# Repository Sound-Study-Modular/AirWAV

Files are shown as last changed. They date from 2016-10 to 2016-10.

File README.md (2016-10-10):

# Sound Study Modular AirWAV

##Information for re-use, adaptations or derivative works

Sound Study Modular is trademarked, and should not be used on any of works you create from these files.

We ask that if you want to re-use all or part of the files provided on github that you change the name of the product to something else

##What is this module?

The Sound Study Modular Air Wav is a virtual radio module, so it behaves a bit like a radio. It is designed to be a source of unexpected audio, not a drum loop player or a sample mangler.

Like a radio, this module works on a series of banks and stations. Each of the 16 banks can contain many different stations. Each station is .raw audio file stored in a bank directory on the SD card. Choose a bank by pressing and holding the RESET switch. Choose a station by turning the STATION knob or plugging a voltage into TUNE.
Detailed controls and displays
Adding samples to the SD Card

Full instructions and tools are in the <a href="http://www.soundstudymodular.com/assembly-instructions/air-wav-assembly-instructions/#sdCard">Setting up the SD Card</a> Section.

##Bank and meter LEDs

The LEDs at the top do two jobs. When audio is playing, they act as a simple VU meter. While choosing banks, they show the bank number in binary

- 0 ○○○○

- 1 ●○○○

- 2 ○●○○

- 3 ●●○○

- 4 ○○●○

- 5 ●○●○

- 6 ○●●○

- 7 ●●●○

- 8 ○○○●

- 9 ●○○●

- 10 ○●○●

- 11 ●●○●

- 12 ○○●●

- 13 ●○●●

- 14 ○●●●

- 15 ●●●●

##Station knob

This is how you choose which file to play from the current folder. It works exactly like a radio tuning knob.

You can put up to 75 files in each folder, but with that many files it might be hard to accurately tune to a station.
If you're between stations, you might get a rapid juddering sound as the module slips between stations. Just retune the knob. If you find it a big problem, put fewer files in each directory so the channels are more spaced out.
Like real radio stations, the files continue to play in the background - they don't re-trigger each time you select a new station.

##Start knob

This knob sets where the file will play from if you press the RESET button. It does nothing until you press the 'Reset' button! (This behaviour can be changed by editing settings.txt)

It's quite a coarse control, with a resolution of 512 steps. So, if you have a 30 minute radio show, the smallest shift you can make will be around 3.5 seconds. If you're playing a 4 second loop, the control will be finer.

##Reset button & LED

TAP the Reset button restarts the current track at the point determined by the Start knob or the Start CV input.

If you're playing a large file (a 30 minute .raw file is 150mb) it will take a few milliseconds to skip to the end of the file, so the button feels less responsive than it does with smaller files, or the earlier parts of bigger files.

HOLD the Reset button for more than 200ms to change banks. Keep the button held down to skip through all 16 banks.

Bank position is saved on the module after power-down.

##SD Card Slot

Full details of the SD file structure are here: <a href="http://www.soundstudymodular.com/assembly-instructions/air-wav-assembly-instructions/#sdCard">SD Card Details</a>

It's possible to hot-swap SD cards. If the module detects the SD card has been removed, it will reboot. When the module boots up, it looks for an SD card for a while - the bank LEDs flash when no card is present. After a while it will give up, and you'll need to turn the power on and off.

##Tune CV Input

This is the CV equivalent of the Station Pot. If the CV changes, the module will immediately re-tune to the relevant station.

The module 'understands' 0v to +5v signals, and is protected against higher or negative voltages.
The CV input is added to the knob position; if the knob is at 12 o'clock and 2.5v is applied to the CV, it's the equivalent of the knob being fully clockwise. Unfortunately you can't 'pull the pot down' by applying a negative voltage.

##Start CV input

This is the CV equivalent of the Start pot. Like the start pot, it does nothing until a 'Reset' CV is received. This CV input behaves like the Tune CV - it's zero to +5v, added to the pot position.
Reset Trigger input

A positive clock here triggers the reset button. It should not trigger the bank change.
##Output

This is a normal modular-level audio output.

The output level is set by the trimmer on the back of the module

The output is AC-coupled so cannot output control voltages

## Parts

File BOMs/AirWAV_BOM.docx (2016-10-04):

# Control Board

Resistors:

QTY | Value | Ref. | Mouser Part #
2 | ‎220Ω | R17, R18 | 291-220-RC
5 | 1.5kΩ | R11, R12, R13, R14, R15 | 291-1.5k-RC
1 | 10kΩ | R8 | 291-10k-RC
2 | 22kΩ | R9, R20 | 291-22k-RC
2 | 47kΩ | R10, R21 | 291-47k-RC
1 | 100kΩ | R19 | 291-100k-RC

TOTAL: 13

Diodes:

QTY | Value | Ref. | Mouser Part #
5 | 3mm Red LED | LED1, LED2, LED3, LED4, LED5 | 604-WP710A10GD
2 | BAT85 | D7, D8 | 78-BAT85S

TOTAL: 7

Potentiometers:

QTY | Value | Ref. | Mouser Part #
2 | B50kΩ | TIME-POT, CHANNEL-POT | Various Suppliers

TOTAL: 2

Jacks/Switches:

QTY | Value | Ref. | Mouser Part #
4 | 3.5mm Mono PJ-301BM-12 Vertical Mount Jack | RESET-CV, TIME-CV, OUTPUT, CHANNEL-CV | PJ301M-12 (Synthrotek or Thonk)
1 | Vertical SD Card Holder | X1 | 945-PJS008U-3000-0
1 | Push Button | RESET | 611-D6R60F1LFS
1 | 11x1 Male Header | JP2 | Synthrotek
1 | 7x1 Male Header | JP4 | Synthrotek

TOTAL: 8

Other:

QTY | Value | Ref. | Mouser Part #
2 | 2.5mm x 6mm Screws | N/A | Synthrotek
2 | 3mm x 6mm Screws | N/A | Synthrotek
1 | PCB & Panel | N/A | Synthrotek
1 | 10 - 16 Pin Power Cable | N/A | Synthrotek

TOTAL: 6

# Logic Board

Resistors:

QTY | Value | Ref. | Mouser Part #
2 | 47Ω | R1, R2 | 291-47-RC
1 | 1kΩ | R7 | 291-1k-RC
2 | 8.2kΩ | R3, R4 | 291-8.2k-RC
1 | 330kΩ | R5 | 291-330k-RC

TOTAL: 6

Diodes:

QTY | Value | Ref. | Mouser Part #
4 | BAT85 | D1, D2, D3, D4 | 78-BAT85S
2 | 1N4002 | D5, D6 | 863-1N4002G

TOTAL: 6

Capacitors:

QTY | Value | Ref. | Mouser Part #
2 | 1nF Ceramic | C1, C4 | 140-50P2-102K-RC
4 | 100nF Ceramic | C2, C3, C5, C8 | 140-50V5-104Z-RC
2 | 10μF Electrolytic | C6, C7 | 667-ECE-A1CKA100

TOTAL: 8

Integrated Circuits:

QTY | Value | Ref. | Mouser Part #
1 | LM78L05 | IC1 | 512-LM78L05ACZ
1 | TL074 | IC4 | 595-TL074CN
1 | 14 Pin DIP Socket | IC4 | 571-1-2199298-3

TOTAL: 3

Potentiometers:

QTY | Value | Ref. | Mouser Part #
1 | B50kΩ Small Box Trimmer | OUTPUT VOLUME | 652-3362P-1-503LF

TOTAL: 1

Jacks/Switches:

QTY | Value | Ref. | Mouser Part #
1 | 11x1 Socket | JP1 | Synthrotek
1 | 7x1 Socket | JP3 | Synthrotek
1 | 14x1 Socket | See Assembly Instructions | Synthrotek
1 | 13x1 Socket | See Assembly Instructions | Synthrotek
1 | 2x1 Socket | See Assembly Instructions | Synthrotek
1 | 14x1 Header | See Assembly Instructions | Synthrotek
1 | 13x1 Header | See Assembly Instructions | Synthrotek
1 | 2x1 Header | See Assembly Instructions | Synthrotek
1 | 5x2 Unshrouded Male Header | POWER | Synthrotek

TOTAL: 6

Other:

QTY | Value | Ref. | Mouser Part #
2 | 200mA Fuse | F1, F2 | 652-MFR020-LF
2 | BL01RNA Ferrite Bead | L1, L2 | 81-BL01RN1A1D2B
1 | Teensy 3.0, 3.1, or 3.2 | TEENSY 3.0, 3.1, or 3.2

TOTAL: 5

Air WAV BOM Updated: 09.07.2016

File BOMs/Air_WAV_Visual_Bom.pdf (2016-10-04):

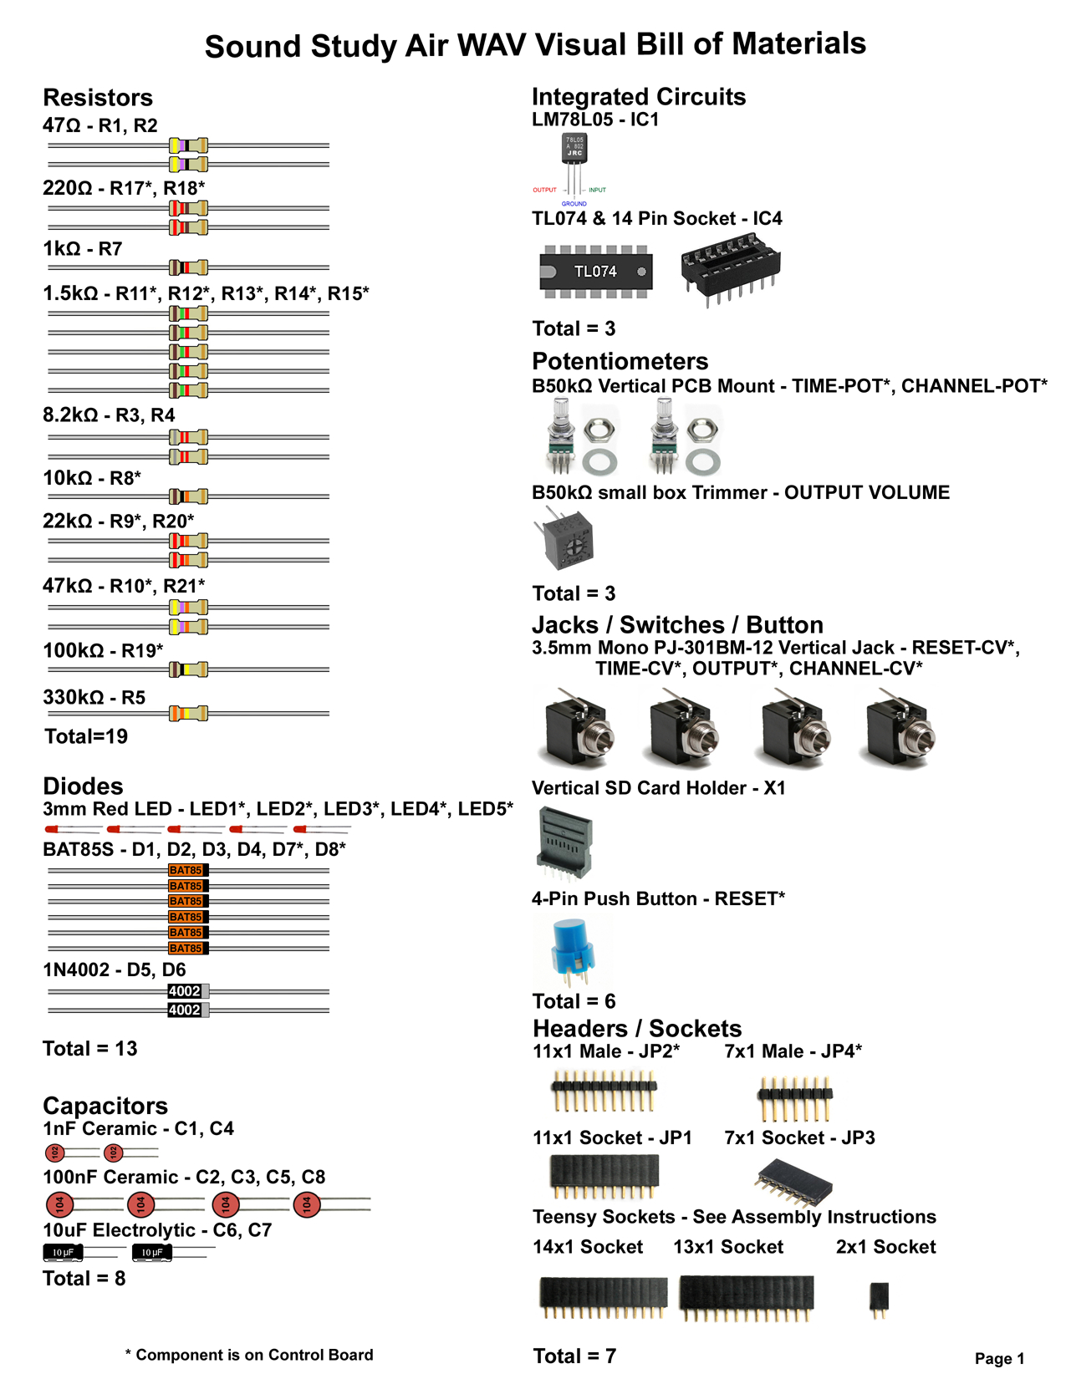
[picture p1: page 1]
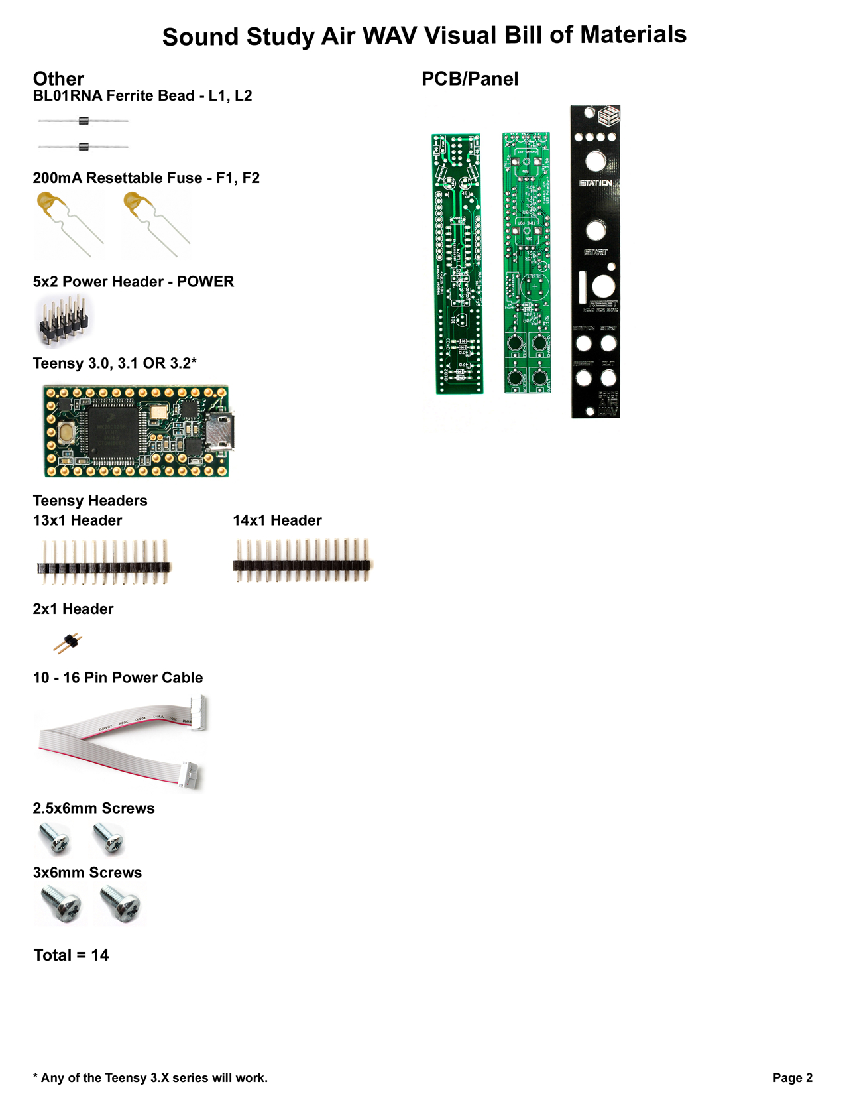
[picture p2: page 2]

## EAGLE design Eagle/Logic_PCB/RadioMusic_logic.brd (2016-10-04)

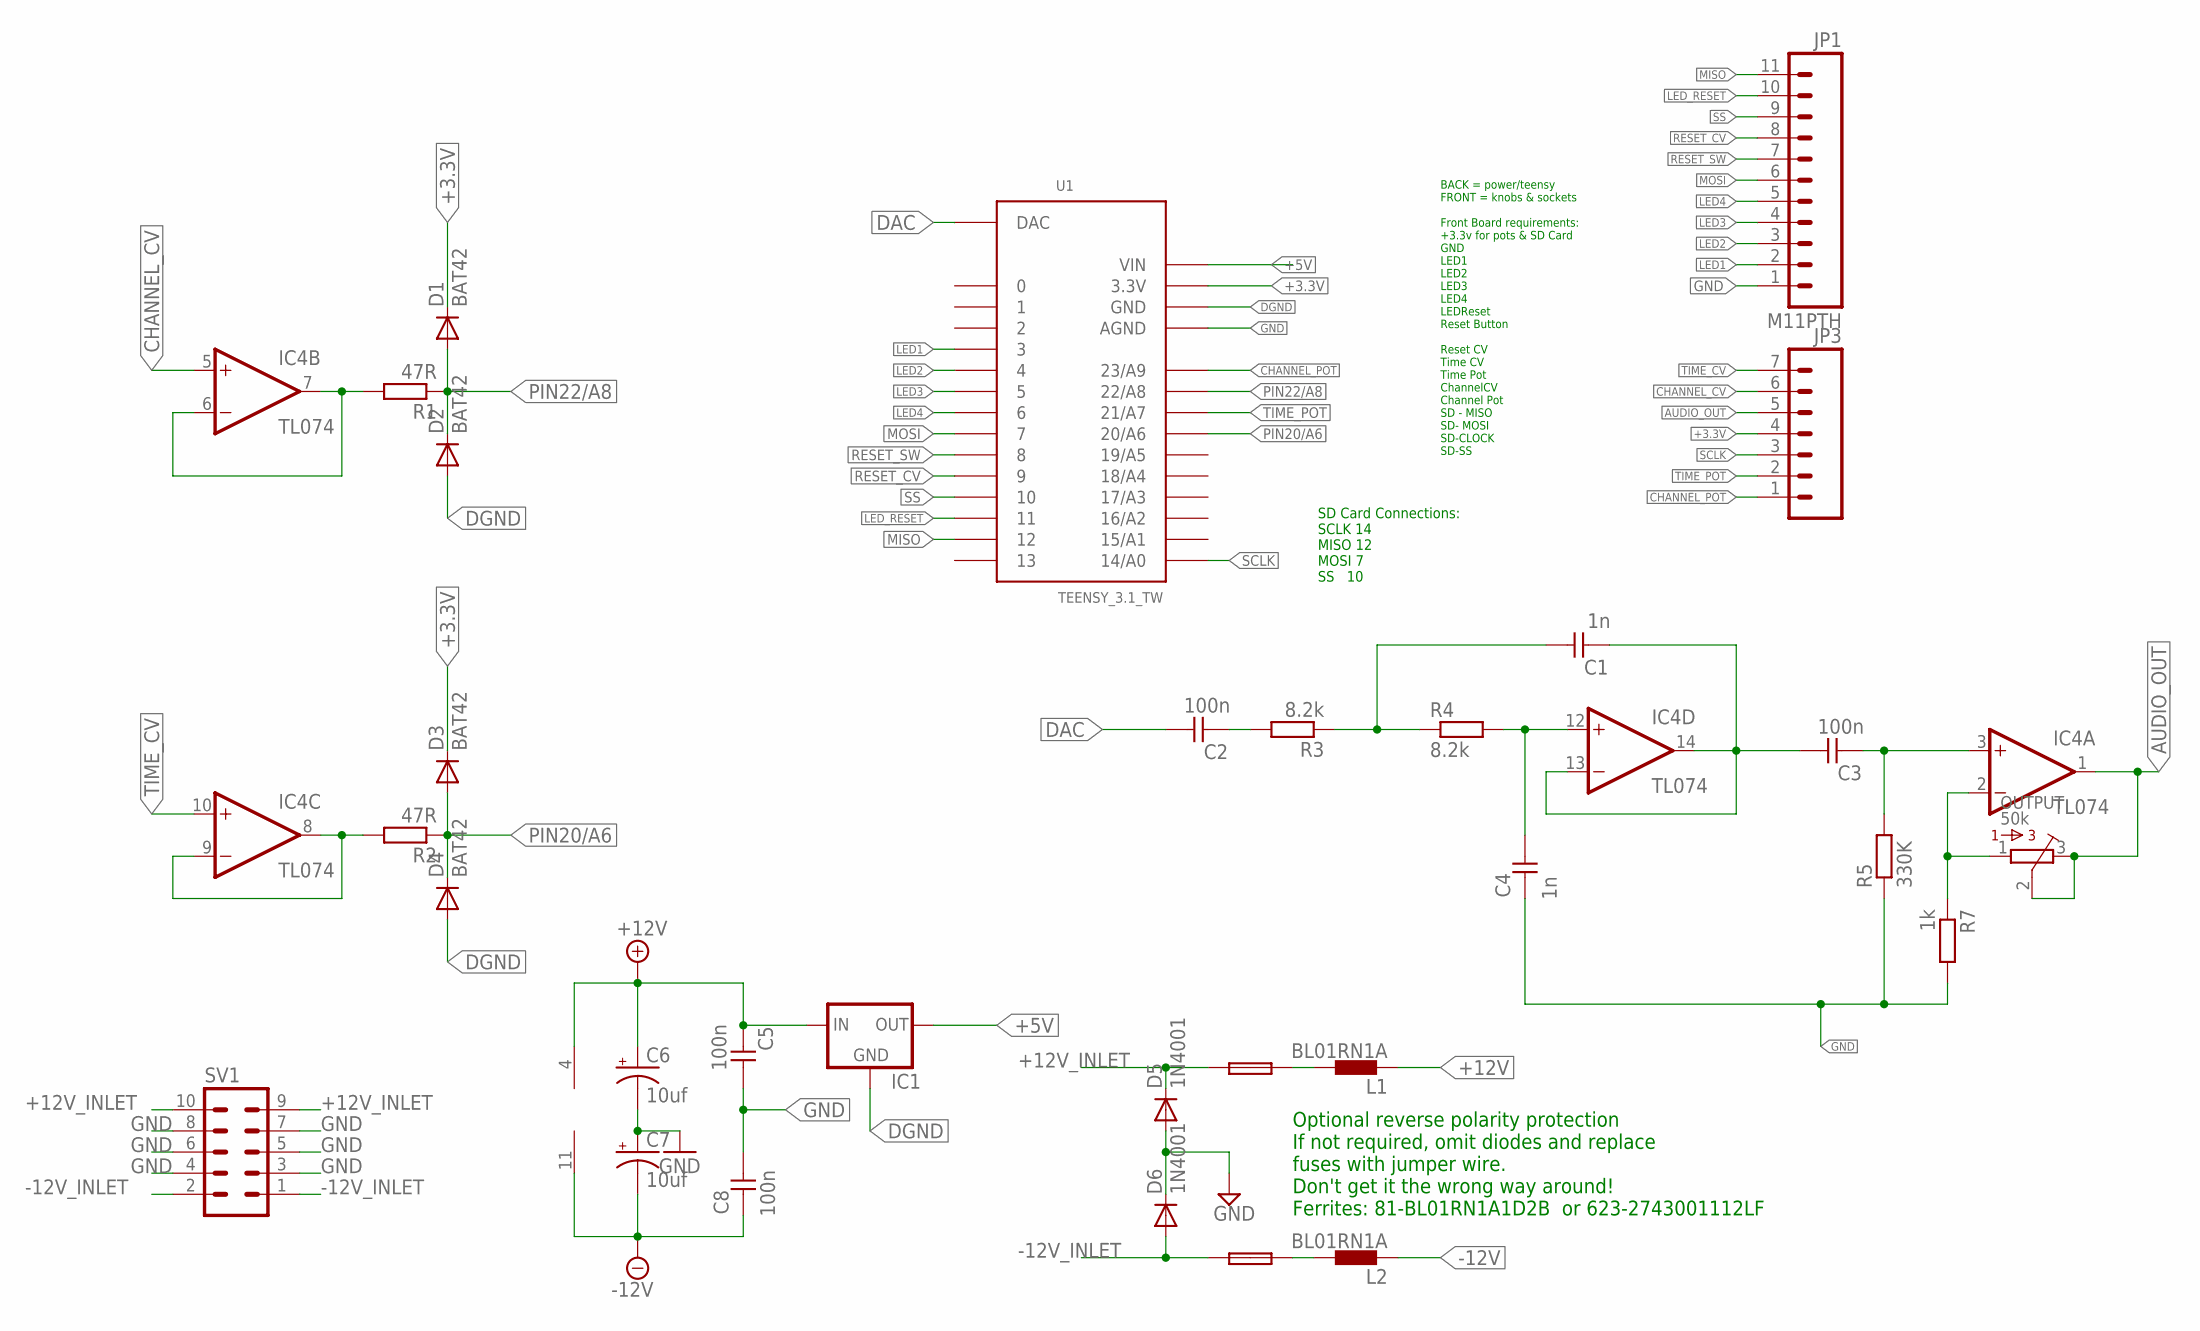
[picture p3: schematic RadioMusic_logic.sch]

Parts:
C1, C4: 1n; C050-024X044
C2, C3: 100n; C050-025X075
C5, C8: 100n; C050-024X044
C6, C7: 10uf; CPOL-RADIAL-10UF-25V
D1, D2, D3, D4: BAT42; DO34-7
D5, D6: 1N4001; DO41-10
F1, F2: FUSE; C050H075X075
IC1: 78LXX
IC4: TL074; DIL14
JP1: M11PTH; 1X11
JP3: M07; 1X07
L1, L2: BL01RN1A
OUTPUT: 50k; 3362P
R1, R2: 47R; 0207/10
R3, R4: 8.2k; 0207/10
R5: 330K; 0207/10
R7: 1k; 0207/10
SV1: 10_PIN_HEADER; MA05-2
U1: TEENSY_3.1_TW

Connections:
+3.3V: D1.C, D3.C, JP3.4, U1.3.3V
+5V: IC1.OUT, U1.VIN
+12V: C5.2, C6.1 (+), IC1.IN, IC4.4 (V+), L1.1
+12V_INLET: D5.C, F1.1, SV1.9, SV1.10
-12V: C7.2 (-), C8.2, IC4.11 (V-), L2.1
-12V_INLET: D6.A, F2.1, SV1.1, SV1.2
AUDIO_OUT: IC4.1 (OUT), JP3.5, OUTPUT.2, OUTPUT.3
CHANNEL_CV: IC4.5 (+IN), JP3.6
CHANNEL_POT: JP3.1, U1.23/A9
DAC: C2.1, U1.DAC
DGND: D2.A, D4.A, IC1.GND, U1.GND
GND: C4.2, C5.1, C6.2 (-), C7.1 (+), C8.1, D5.A, D6.C, JP1.1, R5.1, R7.2, SV1.3, SV1.4, SV1.5, SV1.6, SV1.7, SV1.8, U1.AGND
LED1: JP1.2, U1.3
LED2: JP1.3, U1.4
LED3: JP1.4, U1.5
LED4: JP1.5, U1.6
LED_RESET: JP1.10, U1.11
MISO: JP1.11, U1.12
MOSI: JP1.6, U1.7
unnamed: IC4.8 (OUT), IC4.9 (-IN), R2.2
unnamed: C4.1, IC4.12 (+IN), R4.2
unnamed: IC4.6 (-IN), IC4.7 (OUT), R1.2
unnamed: C1.1, R3.1, R4.1
unnamed: C1.2, C3.1, IC4.13 (-IN), IC4.14 (OUT)
unnamed: C3.2, IC4.3 (+IN), R5.2
unnamed: IC4.2 (-IN), OUTPUT.1, R7.1
unnamed: C2.2, R3.2
unnamed: F1.2, L1.2
unnamed: F2.2, L2.2
PIN20/A6: D3.A, D4.C, R2.1, U1.20/A6
PIN22/A8: D1.A, D2.C, R1.1, U1.22/A8
RESET_CV: JP1.8, U1.9
RESET_SW: JP1.7, U1.8
SCLK: JP3.3, U1.14/A0
SS: JP1.9, U1.10
TIME_CV: IC4.10 (+IN), JP3.7
TIME_POT: JP3.2, U1.21/A7

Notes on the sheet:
Optional reverse polarity protection If not required, omit diodes and replace fuses with jumper wire. Don't get it the wrong way around! Ferrites: 81-BL01RN1A1D2B or 623-2743001112LF
SD Card Connections: SCLK 14 MISO 12 MOSI 7 SS 10
BACK = power/teensy FRONT = knobs & sockets Front Board requirements: +3.3v for pots & SD Card GND LED1 LED2 LED3 LED4 LEDReset Reset Button Reset CV Time CV Time Pot ChannelCV Channel Pot SD - MISO SD- MOSI SD-CLOCK SD-SS

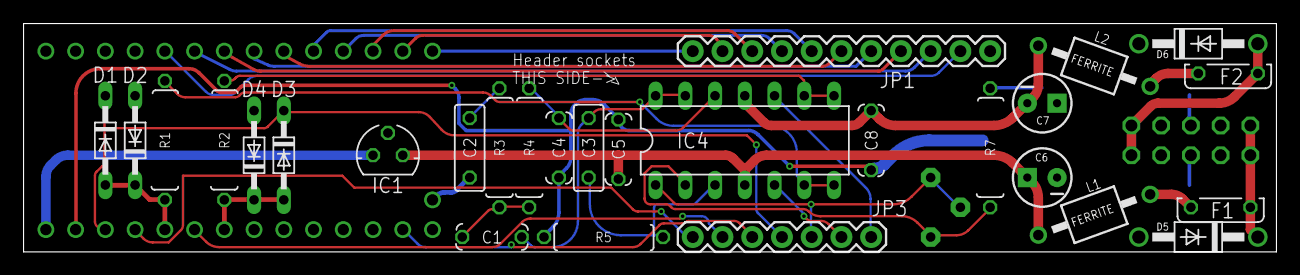
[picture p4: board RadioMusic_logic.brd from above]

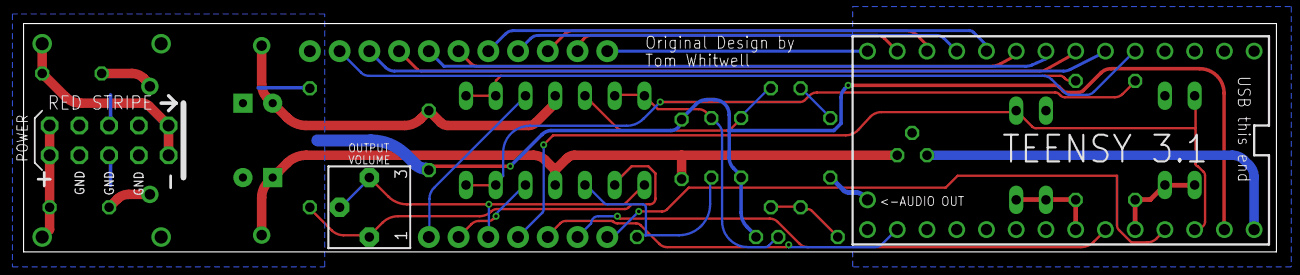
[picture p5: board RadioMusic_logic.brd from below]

Board: 4 copper layers, 107.0 x 19.5 mm, 31 parts (3 on the bottom side), 37 nets.

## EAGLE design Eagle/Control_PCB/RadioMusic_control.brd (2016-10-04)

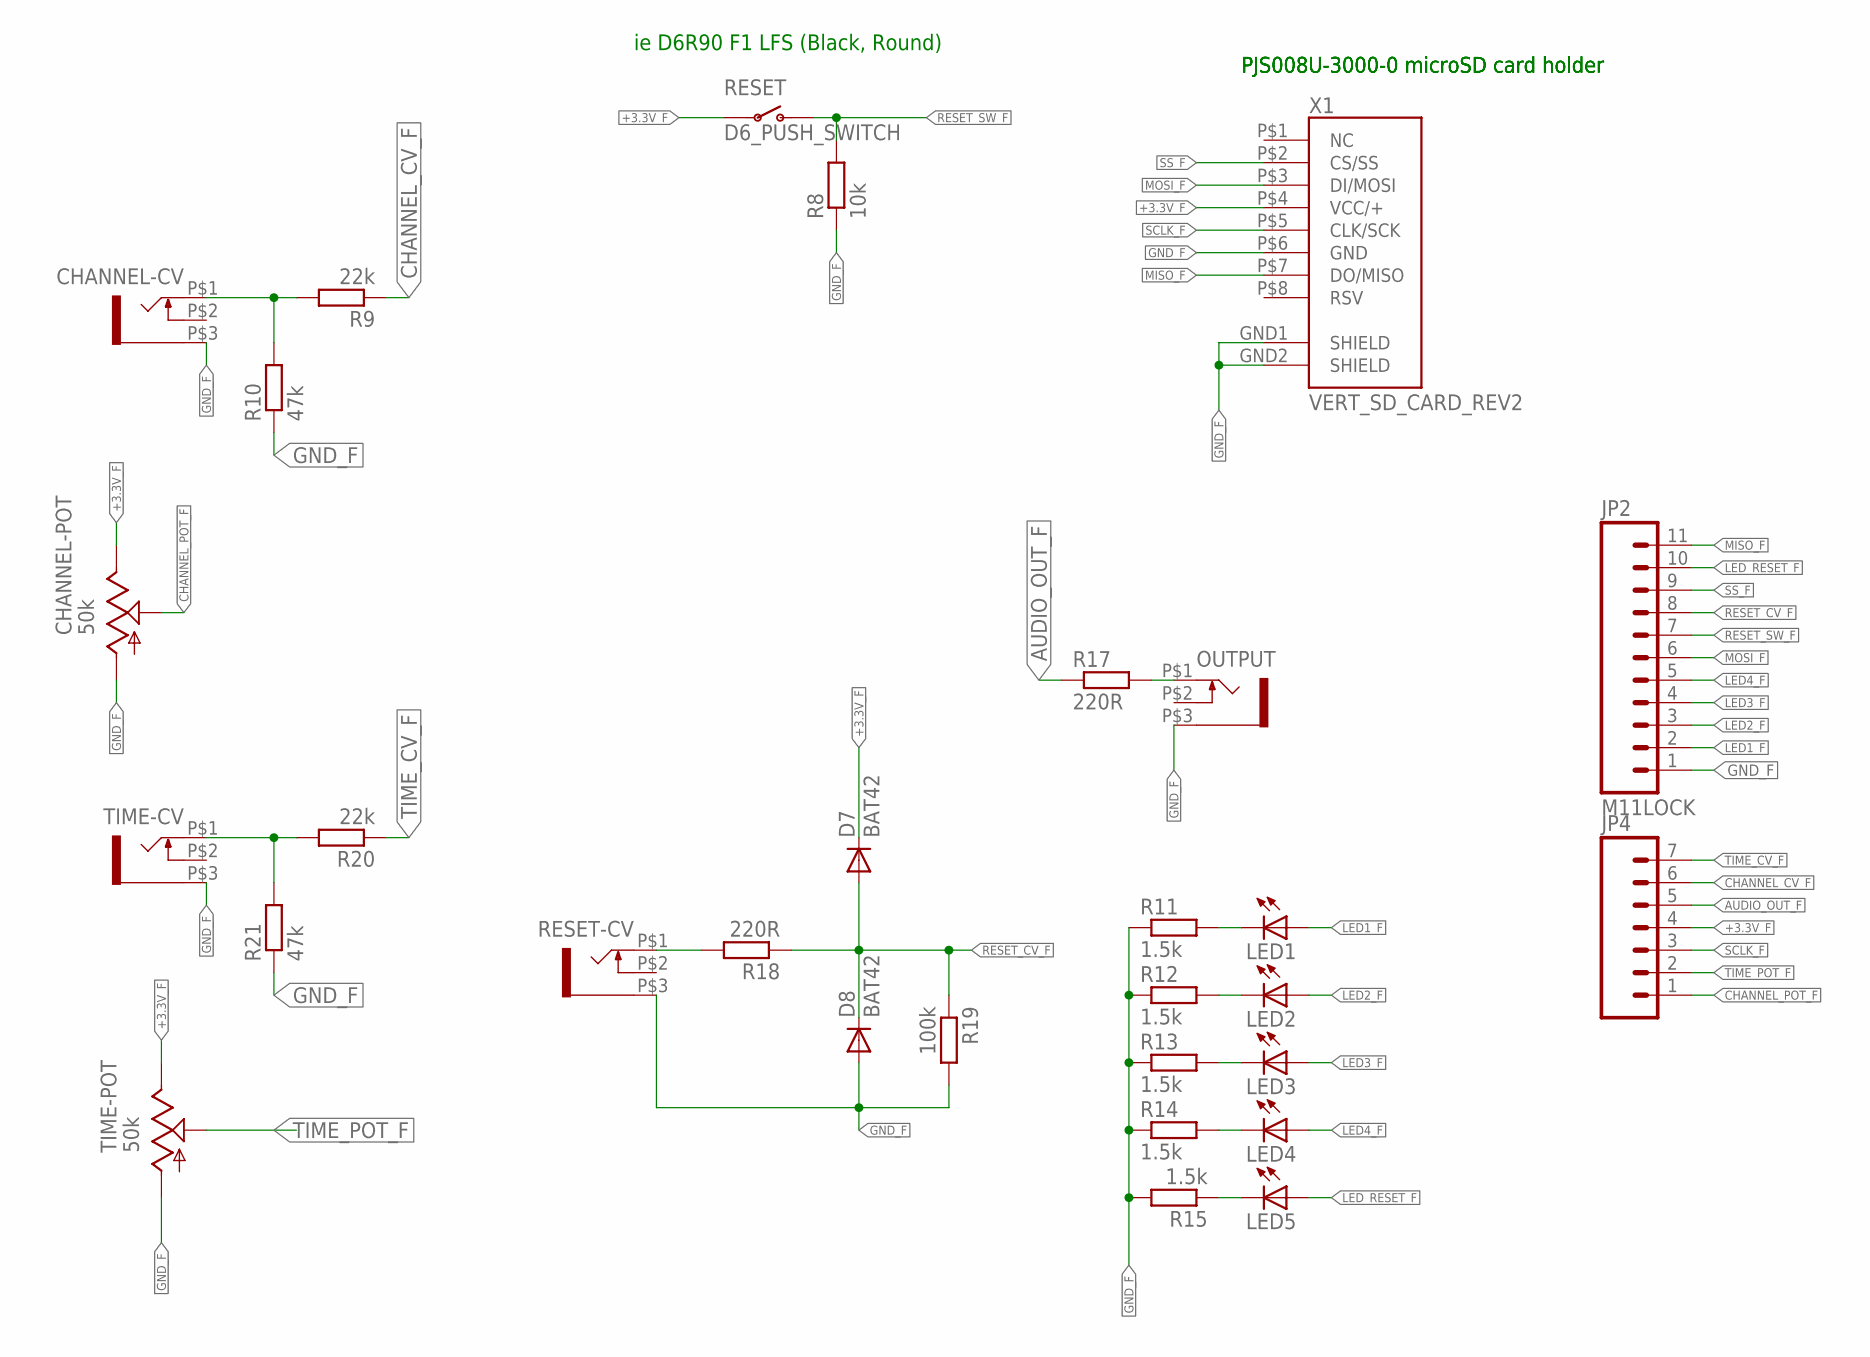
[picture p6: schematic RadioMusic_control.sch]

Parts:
CHANNEL-CV: WQP-PJ301M-12_JACK
CHANNEL-POT: 50k; EVUF
D7, D8: BAT42; DO34-7
JP2: M11LOCK; 1X11_LOCK
JP4: M07LOCK; 1X07_LOCK
LED1, LED2, LED3, LED4, LED5: LED3MM
OUTPUT: WQP-PJ301M-12_JACK
R8: 10k; 0207/10
R9, R20: 22k; 0207/10
R10, R21: 47k; 0207/10
R11, R12, R13, R14, R15: 1.5k; 0207/10
R17, R18: 220R; 0207/10
R19: 100k; 0207/10
RESET: D6_PUSH_SWITCH; D6_BUTTON_RND
RESET-CV: WQP-PJ301M-12_JACK
TIME-CV: WQP-PJ301M-12_JACK
TIME-POT: 50k; EVUF
X1: VERT_SD_CARD_REV2; VERT_MICROSD_REV2

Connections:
+3.3V_F: CHANNEL-POT.3 (E), D7.C, JP4.4, RESET.P$3, RESET.P$4, TIME-POT.3 (E), X1.P$4 (VCC/+)
AUDIO_OUT_F: JP4.5, R17.1
CHANNEL_CV_F: JP4.6, R9.1
CHANNEL_POT_F: CHANNEL-POT.2 (S), JP4.1
GND_F: CHANNEL-CV.P$3 (1), CHANNEL-POT.1 (A), D8.A, JP2.1, OUTPUT.P$3 (1), R8.1, R10.1, R11.1, R12.1, R13.1, R14.1, R15.2, R19.2, R21.1, RESET-CV.P$3 (1), TIME-CV.P$3 (1), TIME-POT.1 (A), X1.GND1 (SHIELD), X1.GND2 (SHIELD), X1.P$6 (GND)
LED1_F: JP2.2, LED1.A
LED2_F: JP2.3, LED2.A
LED3_F: JP2.4, LED3.A
LED4_F: JP2.5, LED4.A
LED_RESET_F: JP2.10, LED5.A
MISO_F: JP2.11, X1.P$7 (DO/MISO)
MOSI_F: JP2.6, X1.P$3 (DI/MOSI)
unnamed: OUTPUT.P$1 (2), R17.2
unnamed: CHANNEL-CV.P$1 (2), R9.2, R10.2
unnamed: R18.2, RESET-CV.P$1 (2)
unnamed: LED1.K (C), R11.2
unnamed: LED2.K (C), R12.2
unnamed: LED3.K (C), R13.2
unnamed: LED4.K (C), R14.2
unnamed: LED5.K (C), R15.1
RESET_CV_F: D7.A, D8.C, JP2.8, R18.1, R19.1
RESET_SW_F: JP2.7, R8.2, RESET.P$1 (O), RESET.P$2 (O)
SCLK_F: JP4.3, X1.P$5 (CLK/SCK)
SS_F: JP2.9, X1.P$2 (CS/SS)
TEMP: R20.2, R21.2, TIME-CV.P$1 (2)
TIME_CV_F: JP4.7, R20.1
TIME_POT_F: JP4.2, TIME-POT.2 (S)

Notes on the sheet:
ie D6R90 F1 LFS (Black, Round)
PJS008U-3000-0 microSD card holder

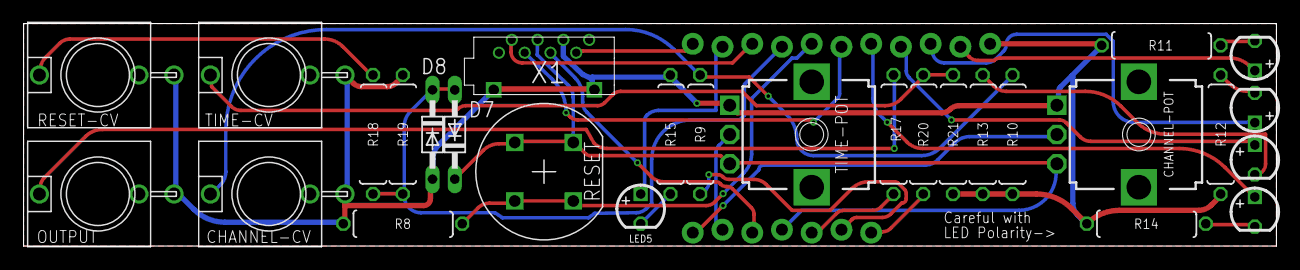
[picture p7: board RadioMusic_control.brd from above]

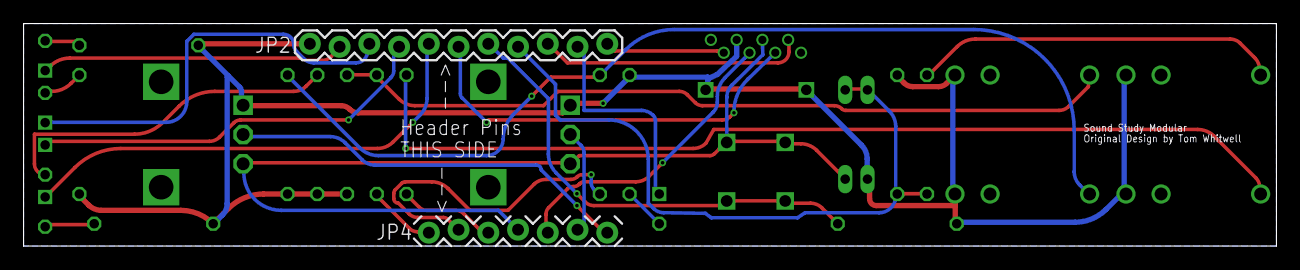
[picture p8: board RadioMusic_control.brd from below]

Board: 4 copper layers, 107.0 x 19.0 mm, 30 parts (2 on the bottom side), 27 nets.

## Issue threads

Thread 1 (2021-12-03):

Incorrect firmware linked

ChrisWeiss, 2021-12-03:
Not quite sure who needs to see this, but the firmware linked on the page http://www.soundstudymodular.com/assembly-instructions/air-wav-assembly-instructions/ does not work for a Teensy 3.2.

Just hoping I can stop someone else from wasting a day resoldering and replacing everything :)

I got working firmware directly from Tom Whitwell's github https://github.com/TomWhitwell/RadioMusic/releases

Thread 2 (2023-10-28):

Intermittent static and/or silence

MrMojoRisinGottaKeepOnRisin, 2023-10-28:
The Sound Study AirWAV BOM has the wrong capacitor types listed for **C2** and **C3**. These should be 100nf **Poly Box Capacitors** but instead they are shown on the BOM as Ceramic Capacitors. I have verified this as an issue after extensive testing. I recently built four AirWAV modules and they all fail 75% of the time if Ceramic Capacitors are used. After using **Poly Box Capacitors** I had a 100% success rate and no issues of any kind. The original Music Thing Modular BOM is at this link and clearly shows **C2** and **C3** as **Poly Box Capacitors**

https://github.com/TomWhitwell/RadioMusic/wiki/BOM---Parts-List

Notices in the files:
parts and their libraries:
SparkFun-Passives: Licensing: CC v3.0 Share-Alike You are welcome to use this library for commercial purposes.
